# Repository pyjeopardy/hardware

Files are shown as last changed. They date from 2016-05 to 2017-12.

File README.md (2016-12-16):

# Jeopardy Hardware

## Parts

### Buzzer

Each part is needed once for one buzzer.

| Part | Shop | Order number | Note |
|---|---|---|---|
| Push button | Conrad  | 701103 - 62  | |
| Case | Conrad  | 1279514 - 62 | Not recommended, has no bottom plate... |
| XLR connector (male) | Conrad  | 651107 - 62  | Neutrik NC3MAAV |
| XLR cable (10m) | Thomann | 128513 | |

### Controller

| Part | Quantity | Shop | Order number  | Note |
|---|---|---|---|---|
| Arduino Micro | 1 | Reichelt | ARDUINO MICRO | |
| Stripboard | 1 | Reichelt | H25SR100 | |
| Socket strip | 3 | Conrad | 736765 - 62 | |
| Pin strip | 2 | Conrad | 737752 - 62 | |
| Case | 1 | Reichelt | TEKO 364 | |
| Wire (yellow) | 1 | Reichelt | LITZE GE | |
| Wire (red) | 1 | Reichelt | LITZE RT | |
| Wire (blue) | 1 | Reichelt | LITZE BL | |
| XLR connector (female) | 18 | Conrad | 651096 - 62 | Neutrik NC3FAAV1 |
| Neutrik screws | 1 | Thomann  | 300310 | A-Screw-1-8 for Neutrik XLR |

Additionally there is a USB-B jack screwed into the case and connected to the
Arduino. The controller then is connected with an USB-A to USB-B cable. This
seems to be a more robust solution than exposing the Micro USB connector of
the Arduino.

## Pin assignment and colors

| Pin | | Color  |
|-----|---|---|
| 1 | GND | blue |
| 2 | +5V | red |
| 3 | Signal | yellow |

To trigger a button, GND and the signal pin need to be connected. +5V are
available since we have a third wire in the XLR cable, maybe it is useful
some day.

On the controller board, the pin next to the Arduino is the signal pin and
and therefore needs to be connected to the yellow wire.

## Notes

 * The internal pull-ups of the Arduino are used
 * The Arduino is not soldered on the board but connected using the socket
   strips, therefore it is quite easy to replace it.
 * The order of the button numbers can be changed in the Arduino sketch in
   `firmware/firmware.ino`. You may need to fix this again after disassembling
   the hardware.

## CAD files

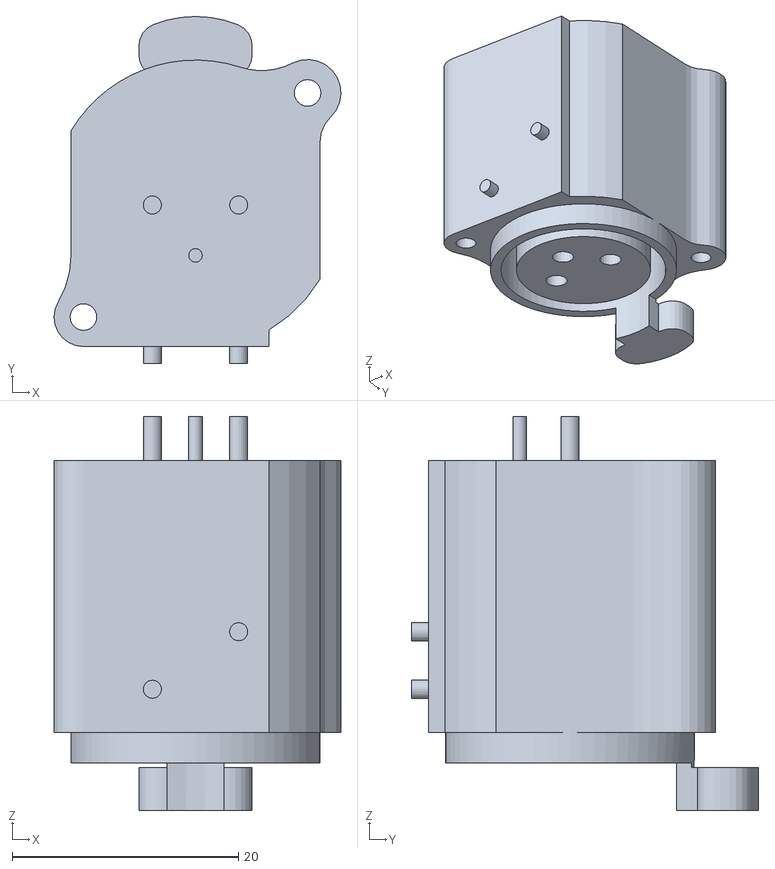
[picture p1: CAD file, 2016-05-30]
case/extern/neutrik.stl
25.3 x 30.6 x 34.8

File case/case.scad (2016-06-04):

draw_parts = 1;
2d = 1;

$fn=20;

// Neutrik NC3FAAV1
module xlr()
{
    color("blue")
    {
        rotate([180, 0, -90])
        import("extern/neutrik.stl");
    }
}

module frontplate()
{
    color("grey") {
        difference() {
            cube([161.5, 304.1, 2]);

            for(x = [30, 80, 130]) {
                for(y = [50-25, 100-25, 150-25, 200-25, 250-25, 300-25]) {
                    translate([x, y, -1]) {
                        cylinder(4, d=22);

                        translate([9.9, 9.9, 0])
                        cylinder(4, d=3.2);

                        translate([-9.9, -9.9, 0])
                        cylinder(4, d=3.2);
                    }
                }
            }
        }

        if(!draw_parts || 2d) {
            for(x = [30, 80, 130]) {
                for(y = [50-25, 100-25, 150-25, 200-25, 250-25, 300-25]) {
                    translate([x, y, 0]) {
                        cylinder(2, d=1);
                    }
                }
            }
        }
    }
}

if(2d) {
    projection() frontplate();
}
else {
    frontplate();
}

if(draw_parts && !2d) {
    for(x = [30, 80, 130]) {
        for(y = [50-25, 100-25, 150-25, 200-25, 250-25, 300-25]) {
            translate([x, y, 0])
            xlr();
        }
    }
}

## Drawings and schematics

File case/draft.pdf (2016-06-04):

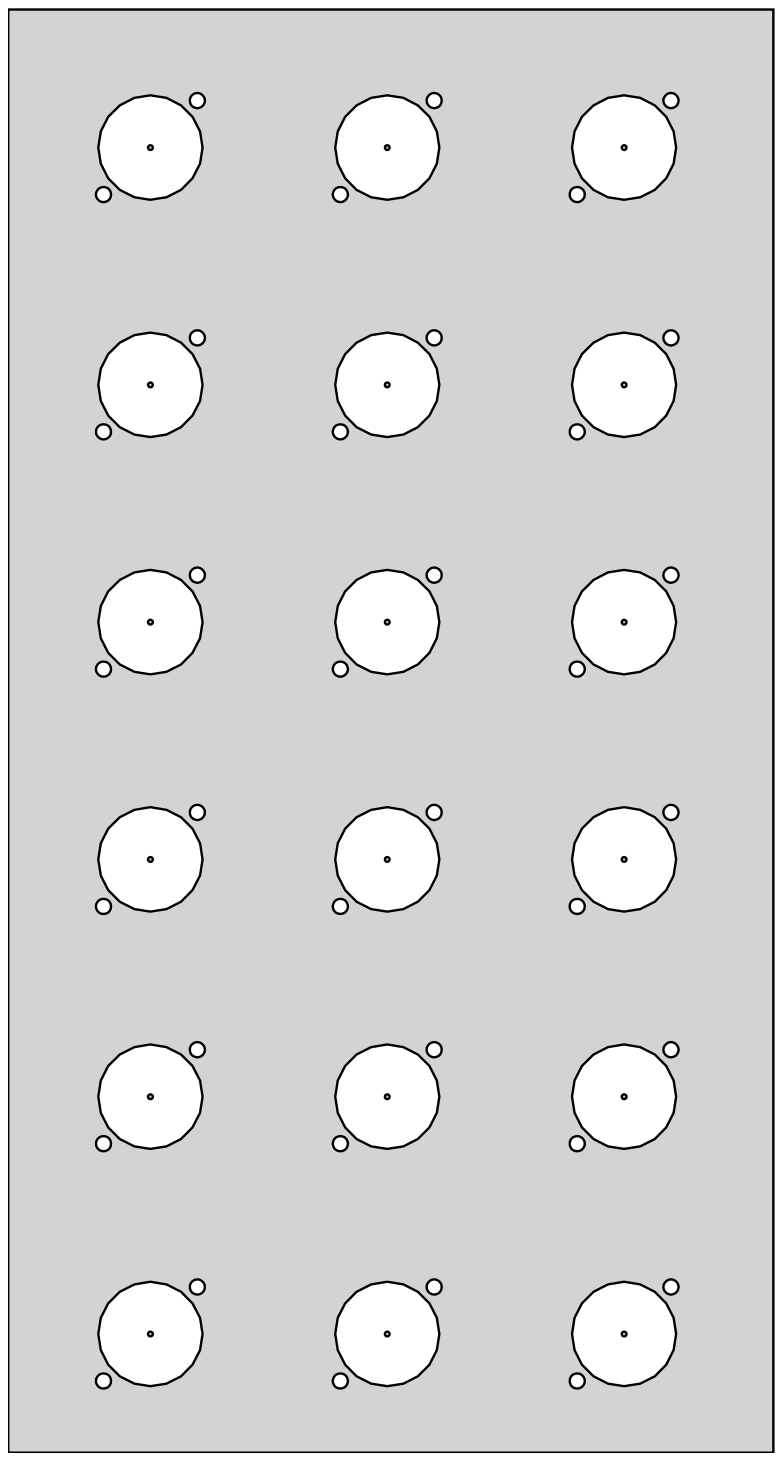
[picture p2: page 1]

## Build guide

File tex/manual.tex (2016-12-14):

\documentclass[12pt,a4paper]{scrartcl}

\usepackage[utf8]{inputenc}

\usepackage{graphicx}
\usepackage{longtable}
\usepackage{color}

\pagenumbering{gobble}

\title{Jeopardy Hardware}
\date{}

\begin{document}
    \maketitle

    \large{
    \begin{longtable}{|l|l|p{7cm}|}
        \hline
        \textbf{Part} & \textbf{Quantity} & \textbf{Image} \\
        \hline
        \endhead
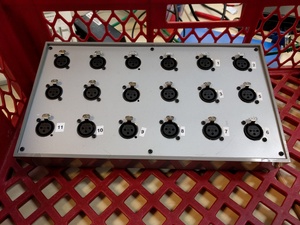
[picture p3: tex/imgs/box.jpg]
        Controller & 1 & \newline \raisebox{-.5\height}{} \newline \\
        \hline
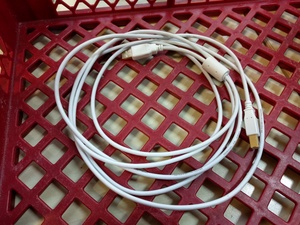
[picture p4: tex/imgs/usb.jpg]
        USB cable & 1 & \newline \raisebox{-.5\height}{} \newline \\
        \hline
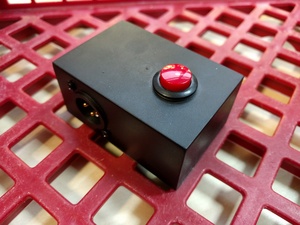
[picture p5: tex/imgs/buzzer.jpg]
        Buzzer & 8 & \newline \raisebox{-.5\height}{} \newline \\
        \hline
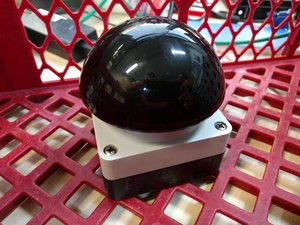
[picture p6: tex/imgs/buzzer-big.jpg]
        Buzzer, big & 1 & \newline \raisebox{-.5\height}{} \newline \\
        \hline
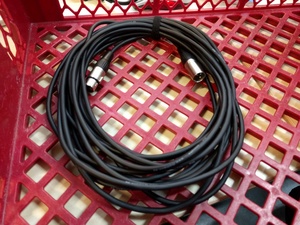
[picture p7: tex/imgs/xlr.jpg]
        XLR cable, 10m & 10 & \newline \raisebox{-.5\height}{} \newline \\
        \hline
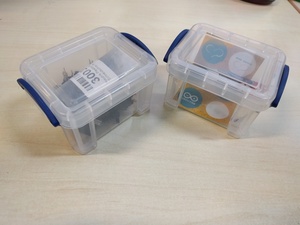
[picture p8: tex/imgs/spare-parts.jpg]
        Spare parts & 2 boxes & \newline \raisebox{-.5\height}{} \newline \\
        \hline
    \end{longtable}
    }
\end{document}

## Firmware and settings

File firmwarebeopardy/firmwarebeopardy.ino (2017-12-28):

// configuration

// the used pins are 0 - 12 and A1 - A4
// there is a connector for A5 on the board, but it did not work and we do not need it
//
// the pins are sorted so that the numbers written on the controller case are correct
// if you change the cabling you might need to sort them again
//int buzzer_pins[] = {0, 1, 2, 3, 4, 5, 6, 7, 8, 9, 10, 11, 12, A0, A1, A2, A3, A4, };
int buzzer_pins[] = {5, 4, 3, 2, 0, 1, A0, A1, A2, A3, A4, 7, 12, 11, 10, 9, 8, 6 };
long debounce_delay = 50;

// internal variables
const int buzzer_pins_count = sizeof(buzzer_pins) / sizeof(int);

int buzzer_last_values[buzzer_pins_count];
int buzzer_debounce[buzzer_pins_count];

int buzzer_first_pressed = 0;

boolean waiting = false;

String input = "";
boolean input_complete = false;


void setup()
{
  Serial.begin(19200);

  input.reserve(200);

  for(int i = 0; i < buzzer_pins_count; i ++)
  {
    pinMode(buzzer_pins[i], INPUT_PULLUP);
    buzzer_last_values[i] = LOW;
    buzzer_debounce[i] = 0;
  }
}


void loop()
{
  update_input();

  update_buzzer();

  if(waiting and buzzer_first_pressed != 0)
  {
    Serial.print(buzzer_first_pressed);
    Serial.print("\n");

    buzzer_first_pressed = 0;
    waiting = false;
  }

  if(input_complete)
  {
    if(input.equals("R")) //reset
    {
      if (buzzer_first_pressed == 0) // no buzzer pressed - Ready 4 Game
      { 
        waiting = true;
        Serial.print("A\n");
      } 
      else   // buzzer pressed - gives idiot who is not releasing it
      { 
        Serial.print(buzzer_first_pressed);
        Serial.print("\n");
      }
    }
    else if(input.equals("A")) // async modus
    {
      Serial.print("A\n");
    }
    else if(input.equals("S") or input.equals("Q")) // sync modus
    {
      Serial.print("ERROR - Sync Mode not supported\n");
    }
    else
      Serial.print("ERROR - unknown command\n");

    input_complete = false;
    input = "";
  }
}


void update_input()
{
  while(Serial.available())
  {
    /*char tmp = Serial.read();

    if (tmp == '\n')
    {
      input_complete = true;
      return;
    }
    else
      input += tmp; */
    if (Serial.available() > 0) {
      char tmp = Serial.read();
      if (tmp != '\r' and tmp != '\n') {
        input += tmp;
        input_complete = true;
      }
    }
  }
}


void update_buzzer()
{
  for(int i = 0; i < buzzer_pins_count; i ++)
  {
    if((millis() - buzzer_debounce[i]) > debounce_delay)
    {
      int value = digitalRead(buzzer_pins[i]);

      if(value != buzzer_last_values[i])
      {
        buzzer_last_values[i] = value;
        buzzer_debounce[i] = millis();

        if(value == HIGH && waiting && buzzer_first_pressed == 0)
          buzzer_first_pressed = i+1;
      }
    }
  }
}

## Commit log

2016-06-04 added firmware
    [case.scad]
2016-06-13 fixed bug in firmware: use only \n as newline
    [firmware.ino]
2017-12-28 shitty arduino gui
